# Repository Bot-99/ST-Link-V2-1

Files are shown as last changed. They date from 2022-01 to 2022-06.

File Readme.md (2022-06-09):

# STLINK-V2.1
## HKUST Robotics Team
## Func
TypeC + STlink + TTL

## cfg
stlink-v2.cfg / stlink-v2_1.cfg

## How to setup
1. connect the swd to other stlink
2. download the firmware
  - open cubeprogrammer / stlink utility
  - connect
  - open the firmware
  - write file (firmware)  
3. desoldering the 0R resistor (R19 R20)

## Source
https://github.com/peng-zhihui/ST-Link-Nano

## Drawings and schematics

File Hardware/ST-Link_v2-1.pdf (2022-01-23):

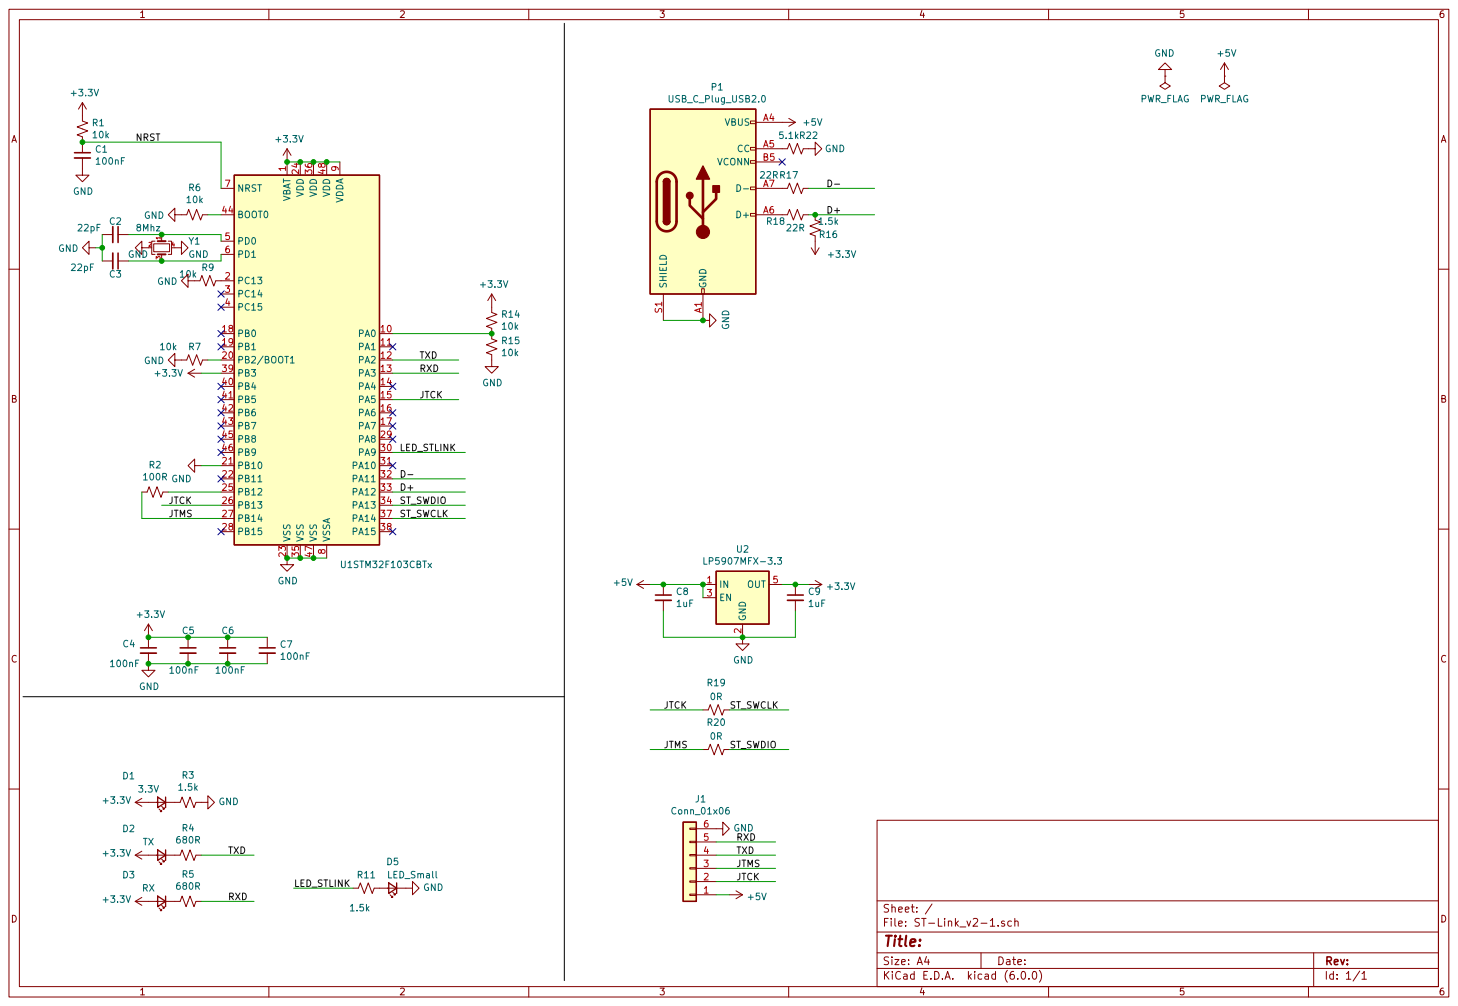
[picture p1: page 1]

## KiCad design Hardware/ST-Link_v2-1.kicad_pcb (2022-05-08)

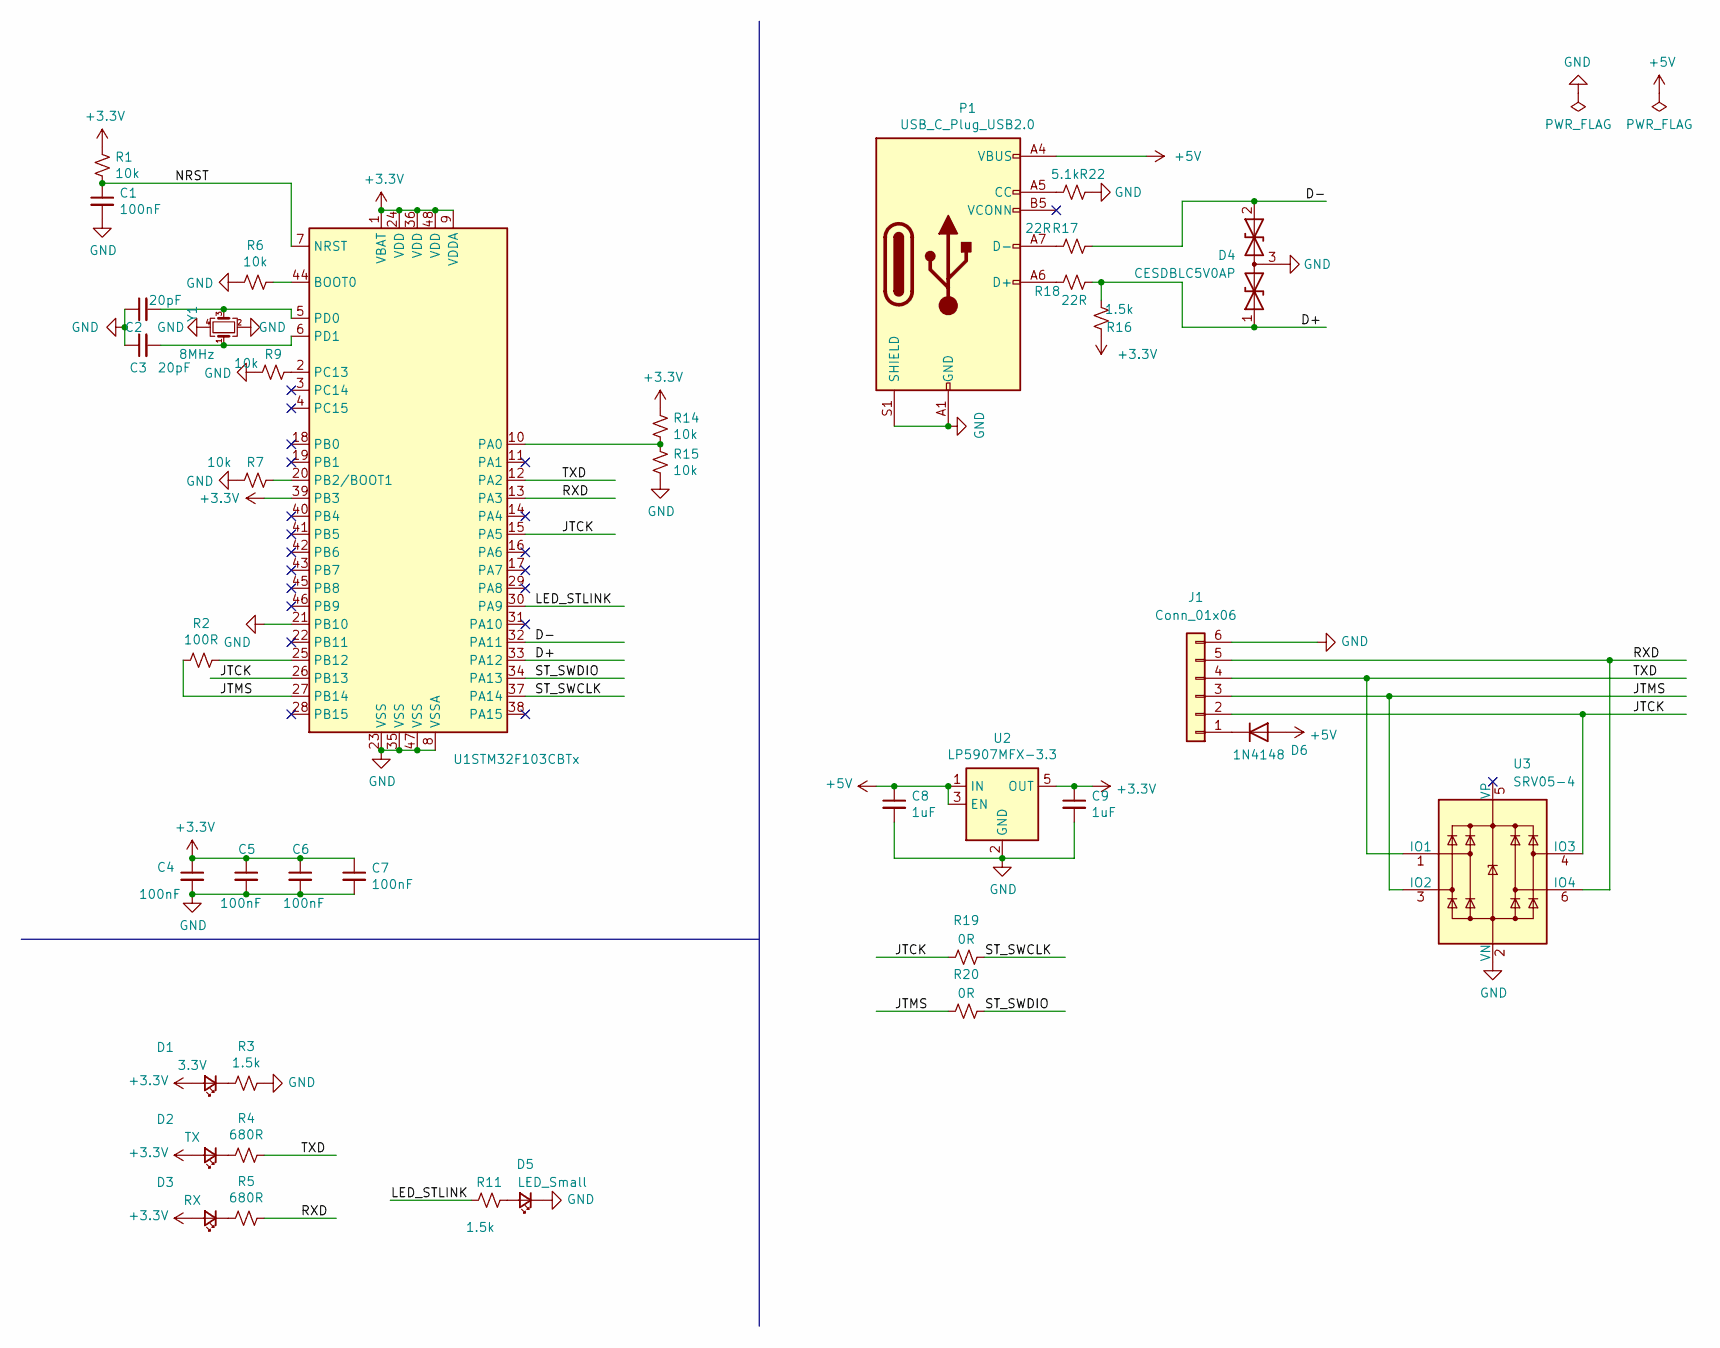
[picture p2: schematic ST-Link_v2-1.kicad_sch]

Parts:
C1, C4, C5, C6, C7: 100nF; C_0603_1608Metric
C2, C3: 20pF; C_0603_1608Metric
C8, C9: 1uF; C_0603_1608Metric
D1: 3.3V; LED_0603_1608Metric
D2: TX; LED_0603_1608Metric
D3: RX; LED_0603_1608Metric
D4: CESDBLC5V0AP; SOT-23
D5: LED_Small; LED_0603_1608Metric
D6: 1N4148; SOD-8OC
J1: Conn_01x06; JST_GH_SM06B-GHS-TB_1x06-1MP_P1.25mm_Horizontal
P1: USB_C_Plug_USB2.0; USB_C_MALE
R1, R6, R7, R9, R14, R15: 10k; R_0603_1608Metric
R2: 100R; R_0603_1608Metric
R3, R11, R16: 1.5k; R_0603_1608Metric
R4, R5: 680R; R_0603_1608Metric
R17, R18: 22R; R_0603_1608Metric
R19, R20: 0R; R_0603_1608Metric
R22: 5.1k; R_0603_1608Metric
U1: STM32F103CBTx; LQFP-48_7x7mm_P0.5mm
U2: LP5907MFX-3.3; SOT-23-5
U3: SRV05-4; SOT-23-6
Y1: 8MHz; Crystal_SMD_3225-4Pin_3.2x2.5mm

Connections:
+3V3: C4.1, C5.1, C6.1, C7.1, C9.1, D1.2 (A), D2.2 (A), D3.2 (A), R1.2, R14.2, R16.1, U1.1 (VBAT), U1.9 (VDDA), U1.24 (VDD), U1.36 (VDD), U1.39 (PB3), U1.48 (VDD), U2.5 (OUT)
+5V: C8.1, D6.2 (A), P1.A4 (VBUS), P1.A9 (VBUS), P1.B4 (VBUS), P1.B9 (VBUS), U2.1 (IN), U2.3 (EN)
/D+: D4.1 (A1), R16.2, R18.1, U1.33 (PA12)
/D-: D4.2 (A2), R17.1, U1.32 (PA11)
/JTCK: J1.2, R19.2, U1.15 (PA5), U1.26 (PB13), U3.4 (IO3)
/JTMS: J1.3, R2.2, R20.2, U1.27 (PB14), U3.3 (IO2)
/LED_STLINK: R11.2, U1.30 (PA9)
/NRST: C1.1, R1.1, U1.7 (NRST)
/RXD: J1.5, R5.1, U1.13 (PA3), U3.6 (IO4)
/ST_SWCLK: R19.1, U1.37 (PA14)
/ST_SWDIO: R20.1, U1.34 (PA13)
/TXD: J1.4, R4.1, U1.12 (PA2), U3.1 (IO1)
GND: C1.2, C2.1, C3.1, C4.2, C5.2, C6.2, C7.2, C8.2, C9.2, D4.3 (common), D5.1 (K), J1.6, P1.A1 (GND), P1.A12 (GND), P1.B1 (GND), P1.B12 (GND), P1.S1 (SHIELD), R3.1, R6.2, R7.2, R9.2, R15.1, R22.2, U1.8 (VSSA), U1.21 (PB10), U1.23 (VSS), U1.35 (VSS), U1.47 (VSS), U2.2 (GND), U3.2 (VN), Y1.2, Y1.4
unnamed: D1.1 (K), R3.2
unnamed: D2.1 (K), R4.2
unnamed: D3.1 (K), R5.2
unnamed: D5.2 (A), R11.1
unnamed: D6.1 (K), J1.1
unnamed: P1.A5 (CC), R22.1
unnamed: P1.A6 (D+), R18.2
unnamed: P1.A7 (D-), R17.2
unnamed: R2.1, U1.25 (PB12)
unnamed: R6.1, U1.44 (BOOT0)
unnamed: R7.1, U1.20 (PB2/BOOT1)
unnamed: R9.1, U1.2 (PC13)
unnamed: R14.1, R15.2, U1.10 (PA0)
unnamed: C2.2, U1.5 (PD0), Y1.3
unnamed: C3.2, U1.6 (PD1), Y1.1

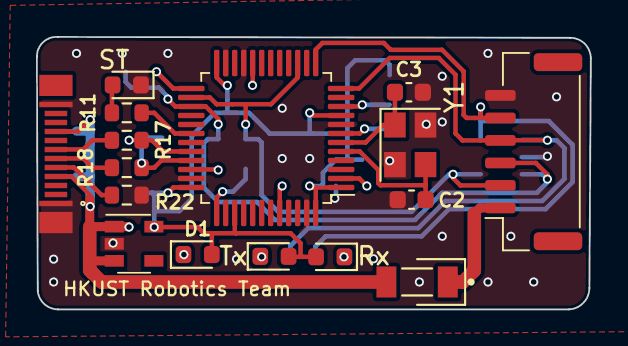
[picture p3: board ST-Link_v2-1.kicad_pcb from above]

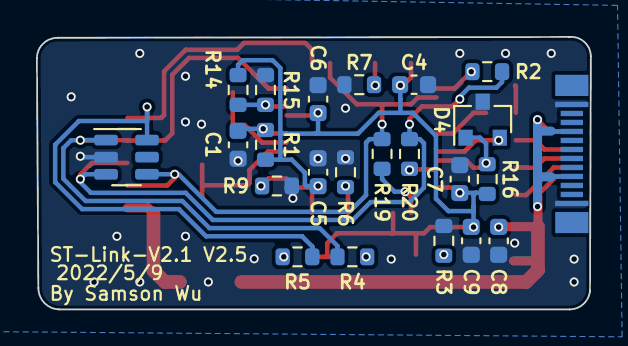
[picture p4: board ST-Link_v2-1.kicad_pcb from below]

Board: 2 copper layers, 30.8 x 15.1 mm, 38 parts (22 on the bottom side), 28 nets.

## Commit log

2021-12-01 v2 2/12/2021
    [ST-Link_v2-1.kicad_pcb, ST-Link_v2-1.sch]
2021-12-03 find bug in sch
    [ST-Link_v2-1.kicad_pcb, ST-Link_v2-1.sch]
2021-12-10 V2.1 11/12/2021
    [ST-Link_v2-1.kicad_pcb, ST-Link_v2-1.sch]
2022-04-11 2.4 add esd protection
    [ST-Link_v2-1.kicad_pcb]
2022-04-11 2.4 desgin rule check
    [ST-Link_v2-1.kicad_pcb]
